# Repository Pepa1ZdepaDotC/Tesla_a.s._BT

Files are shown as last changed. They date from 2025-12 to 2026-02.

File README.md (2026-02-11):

# Tesla 1128A repair and BT upgrade

[Schematic](https://github.com/Pepa1ZdepaDotC/Tesla_BT/blob/main/Tesla_rev_2/Tesla_sextant_BT.pdf)

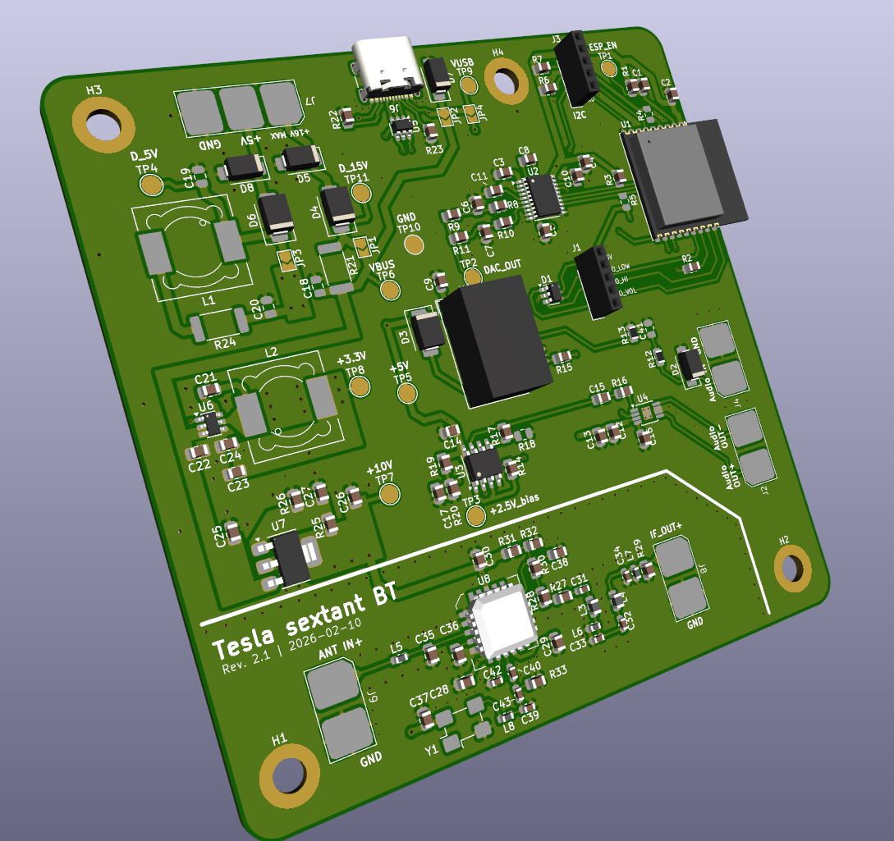
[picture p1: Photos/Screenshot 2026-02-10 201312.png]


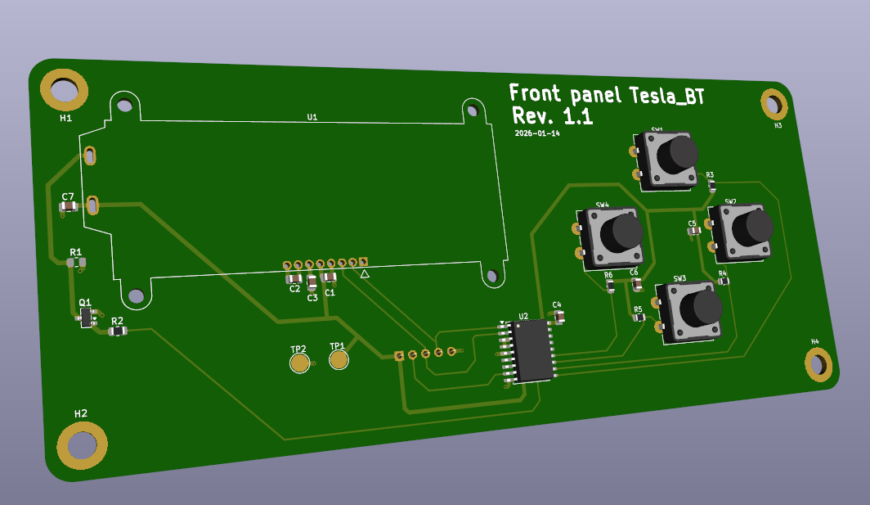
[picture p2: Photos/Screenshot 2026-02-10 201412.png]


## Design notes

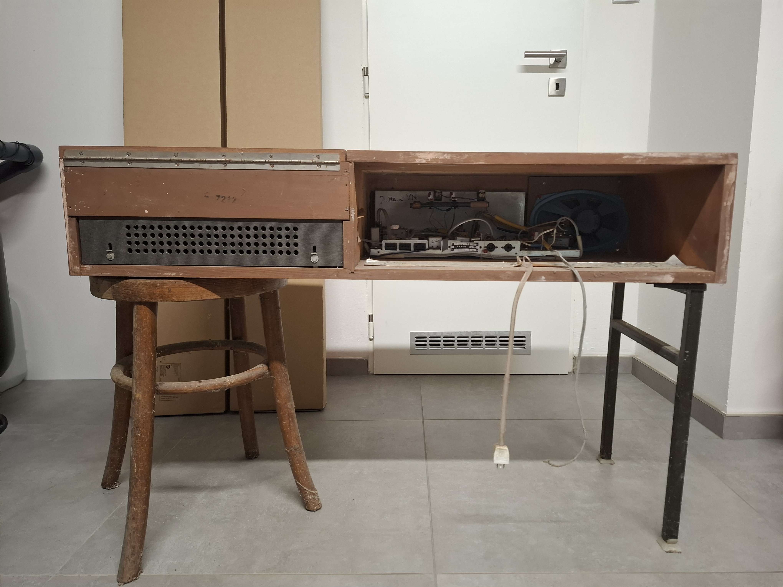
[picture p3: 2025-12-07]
Photos/Back.jpg

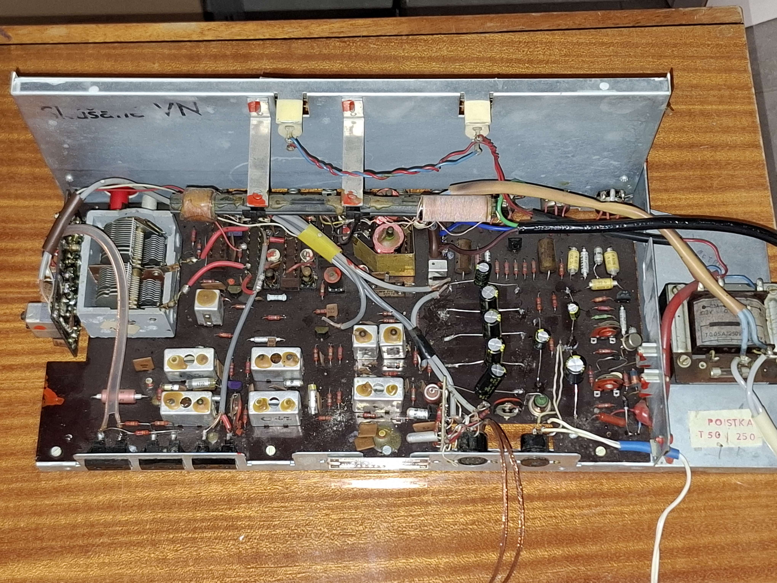
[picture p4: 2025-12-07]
Photos/Up.jpg

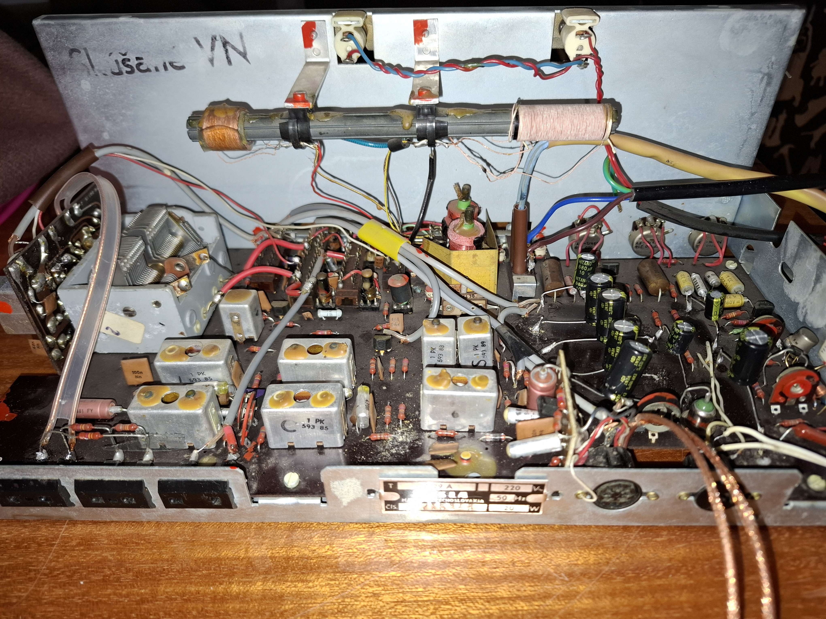
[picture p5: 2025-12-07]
Photos/Side.jpg

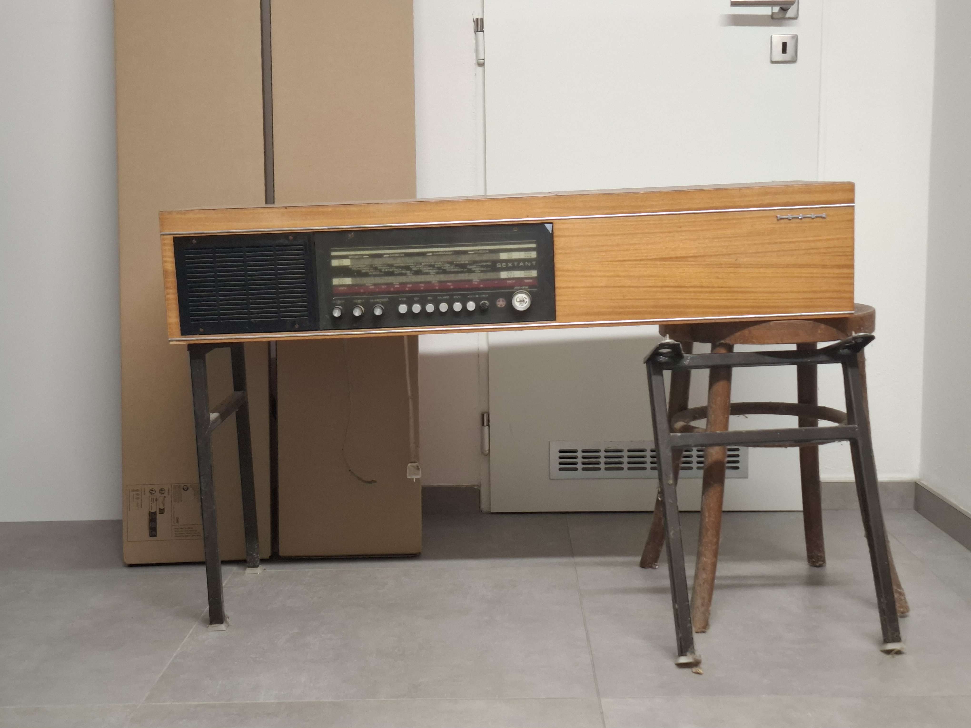
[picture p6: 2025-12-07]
Photos/Front.jpg

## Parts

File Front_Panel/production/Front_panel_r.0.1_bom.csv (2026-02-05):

Designator | Footprint | Quantity | Value | LCSC Part #
C1, C2, C3, C7 | 0805 | 4 | 470nF
C4, C5, C6 | 0805 | 3 | 100nF
J2 | PinSocket_1x05_P2.54mm_Vertical | 1 | Conn_01x05
Q1 | SOT-23 | 1 | BC817
R1 | 0805 | 1 | 0R
R2 | 0805 | 1 | 1K
R3, R4, R5, R6 | 0805 | 4 | 10K
SW1, SW2, SW3, SW4 | SW_PUSH-12mm_Wuerth-430476085716 | 4 | SW_Push
TP1, TP2 | TestPoint_Pad_D3.0mm | 2 | TestPoint
U1 | NHD-C0220BiZ | 1 | NHD-C0220BIZ
U2 | SOIC-18W_7.5x11.6mm_P1.27mm | 1 | MCP23008-xSO

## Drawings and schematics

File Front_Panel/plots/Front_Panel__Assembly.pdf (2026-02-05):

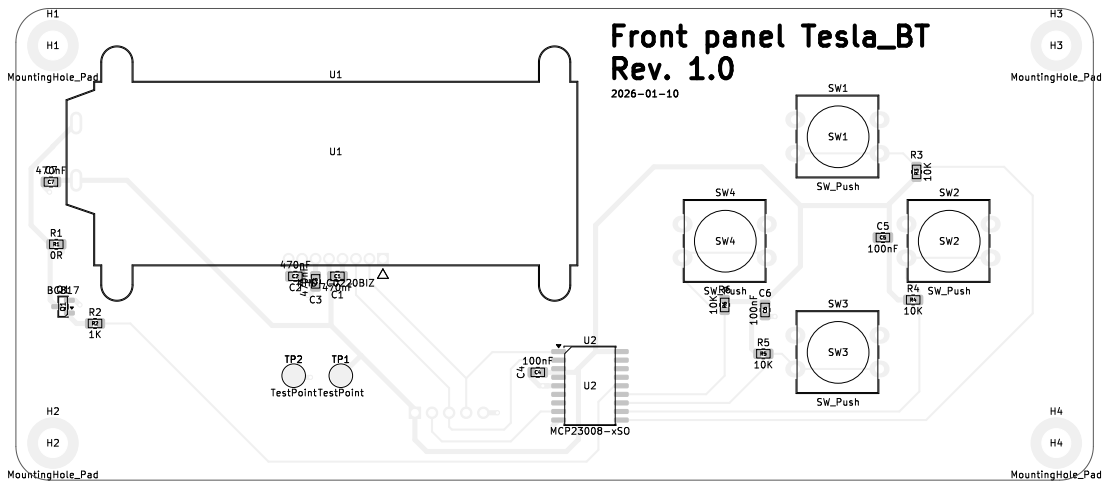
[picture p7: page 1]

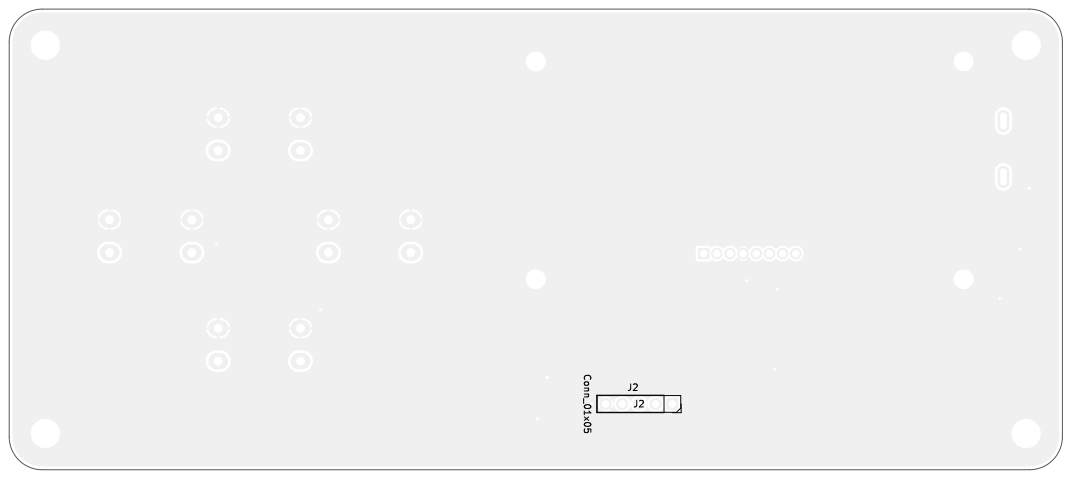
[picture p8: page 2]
D Date: 2026-01-10 KiCad; E.D.A. 9.0.7 Size: A4; Rev: 1.0; Id: /1 Title: Front panel File: Front_Panel.kicad_pcb Sheet: Black; And; White; BOT Board2Pdf:; Black; BOT -; Page 2/2 Conn_01x05

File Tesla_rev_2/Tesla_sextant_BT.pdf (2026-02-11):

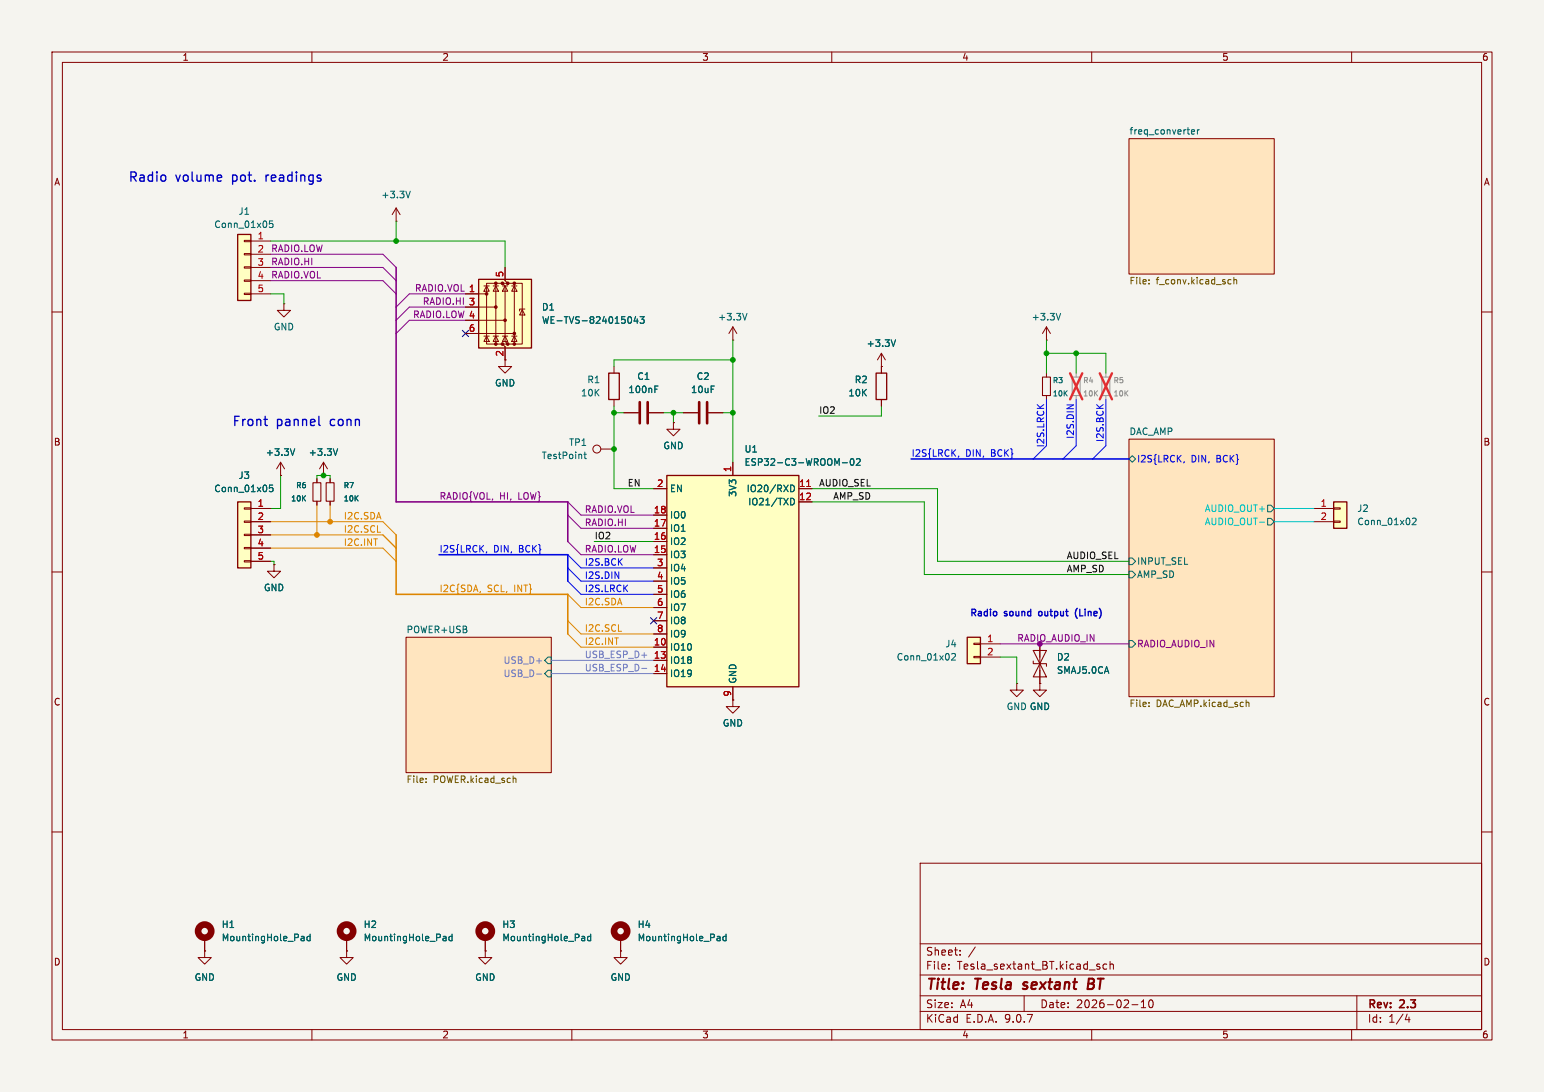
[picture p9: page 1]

I2S.BCK Front pannel conn Radio volume pot. readings
I2C.SCL RADIO.VOL
+3.3V GND

Radio sound output (Line) C2

File: Tesla_sextant_BT.kicad_sch Sheet: / USB_D+ USB_D- POWER+USB

Id: 1/4 Title: Tesla sextant BT

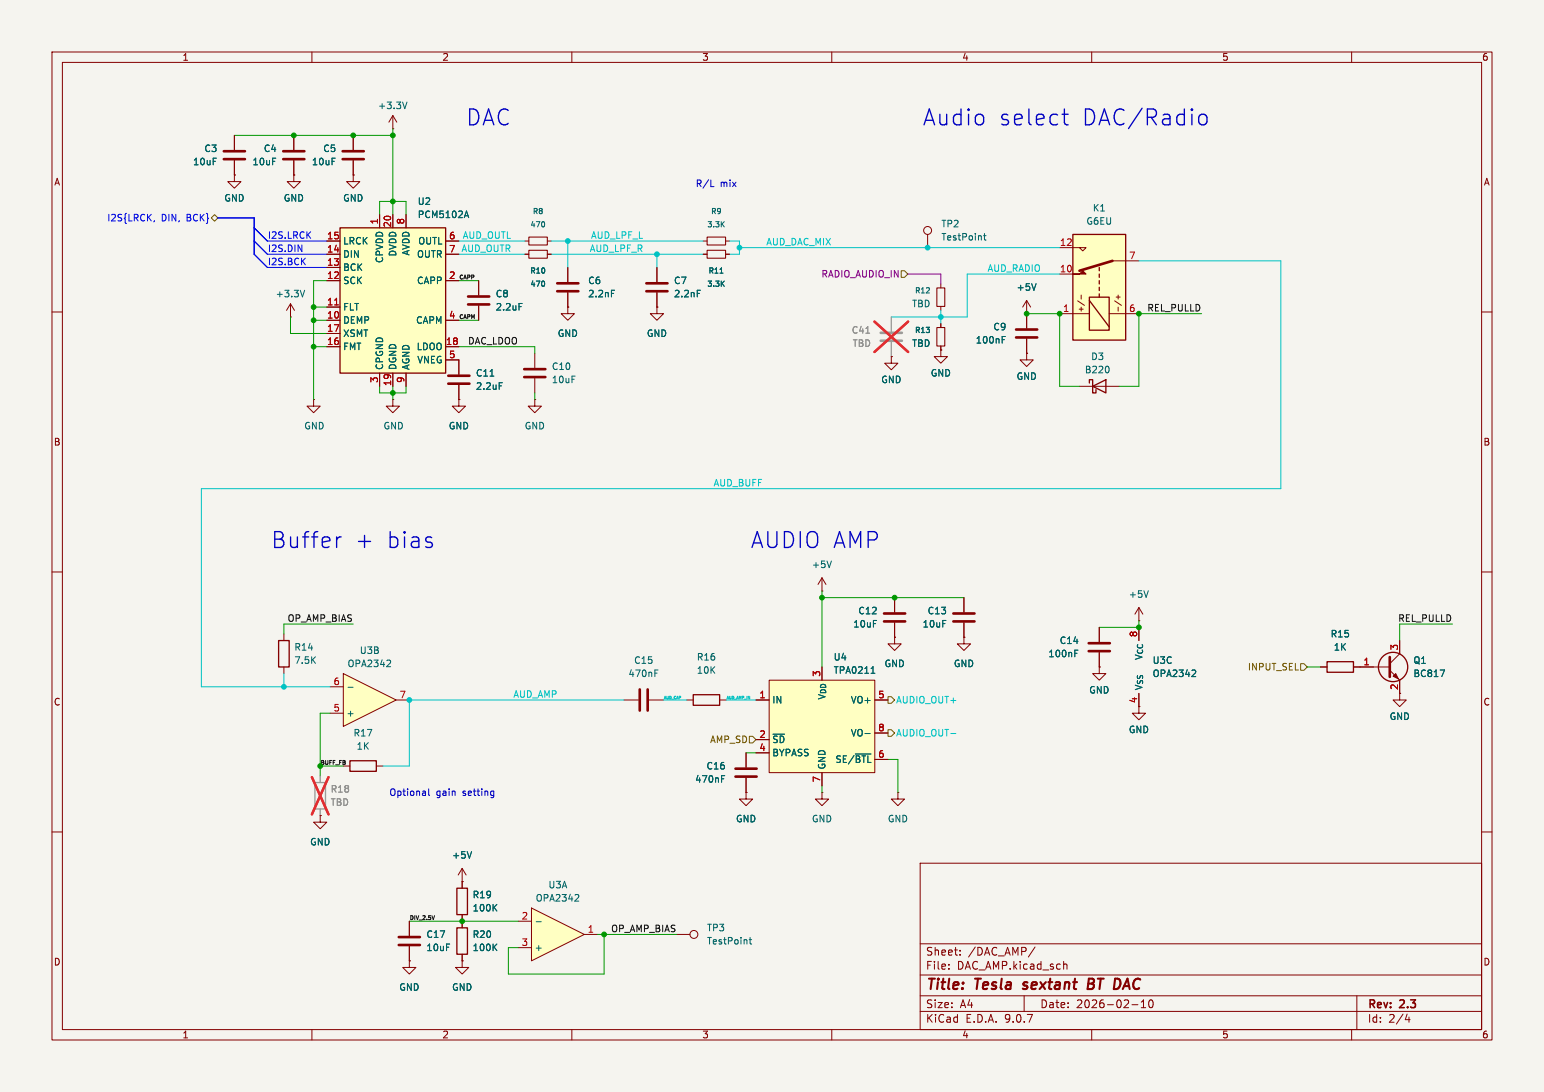
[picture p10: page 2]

9 OUTL 6 OUTR 7 CAPP 2 CAPM 4
2.2uFC8

7 VO+ 5 VO- 8 SE/~{BTL}6 U4 TPA0211

7 VO+ 5 VO- 8 SE/~{BTL}6 R19

File: DAC_AMP.kicad_sch Sheet: /DAC_AMP/
Id: 2/4 Title: Tesla sextant BT DAC

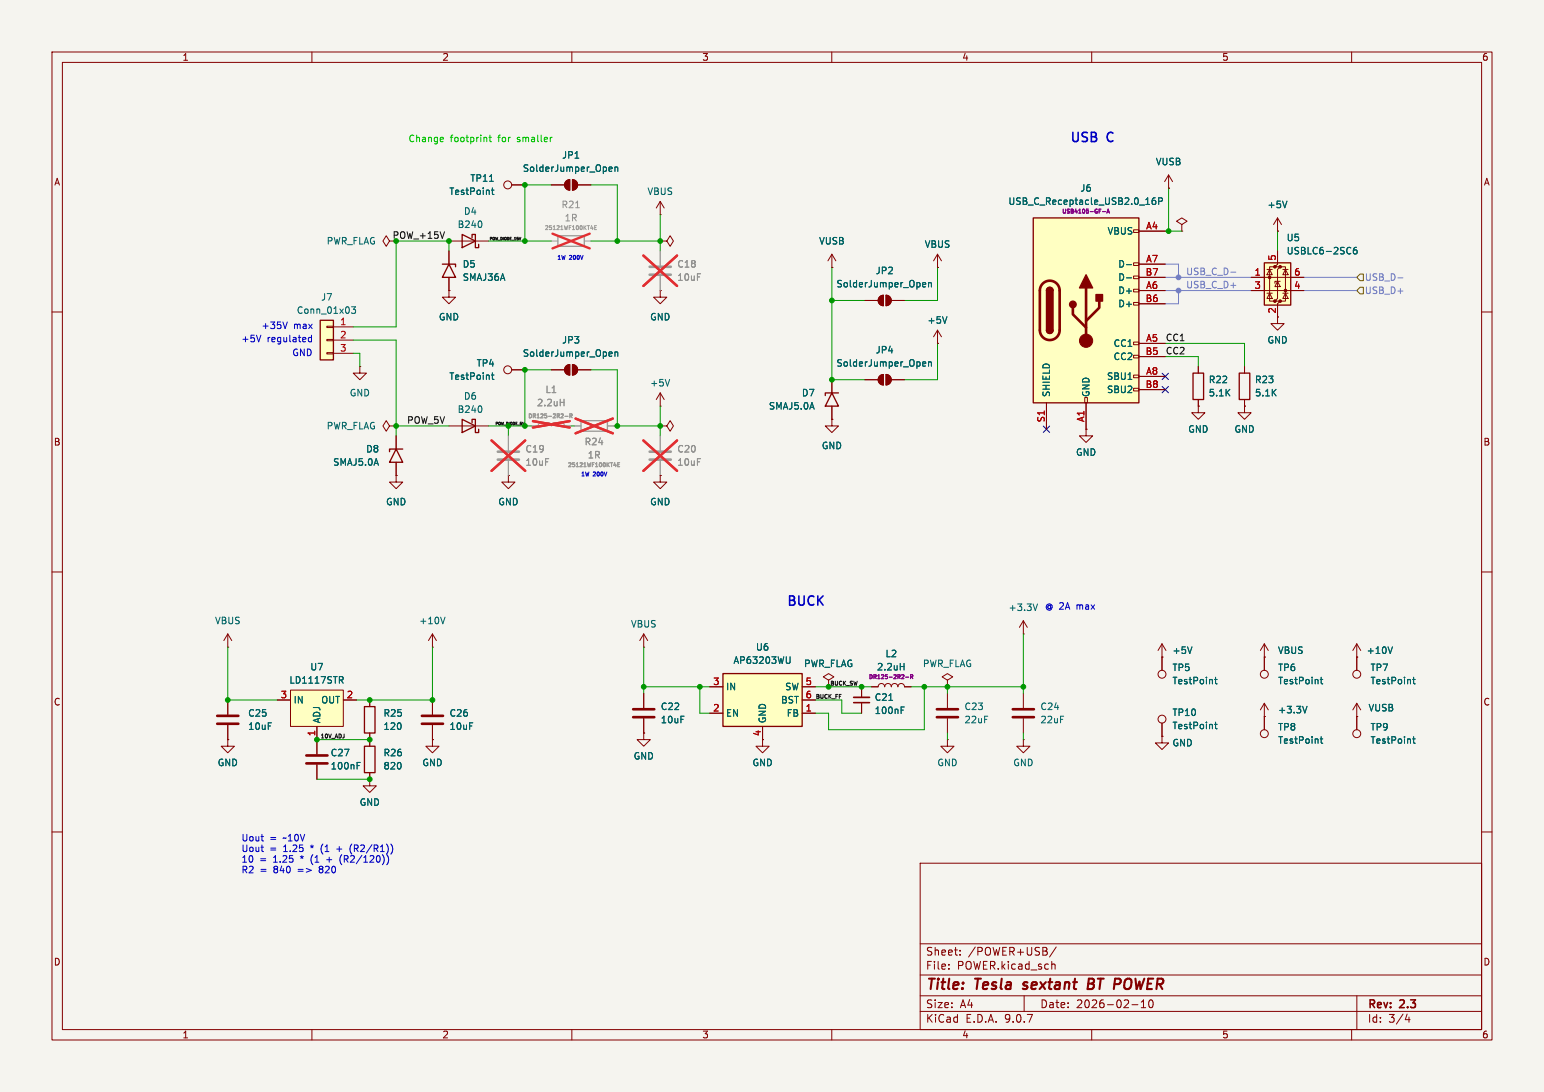
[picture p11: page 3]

4 SW 5 BST 6 FB 1 U6 AP63203WU GND GND

4 SW 5 BST 6 FB 1 GND

File: POWER.kicad_sch Sheet: /POWER+USB/
Id: 3/4 Title: Tesla sextant BT POWER

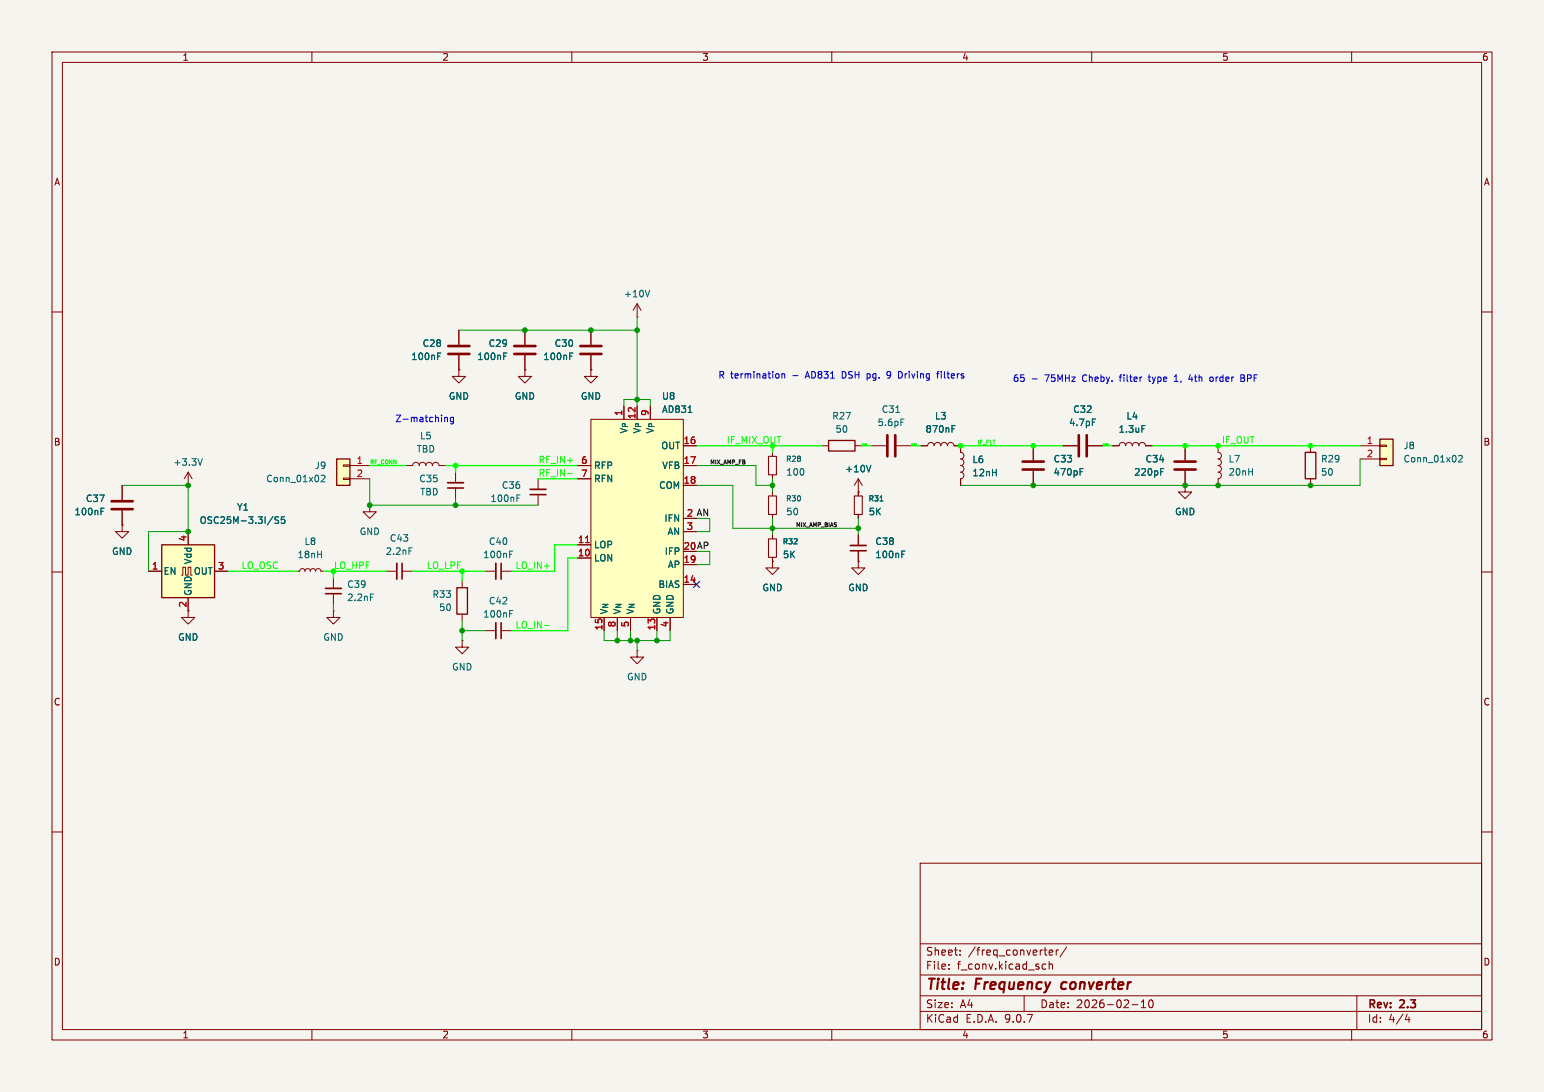
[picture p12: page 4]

Id: 4/4 Title: Frequency converter File: f_conv.kicad_sch Sheet: /freq_converter/ GND

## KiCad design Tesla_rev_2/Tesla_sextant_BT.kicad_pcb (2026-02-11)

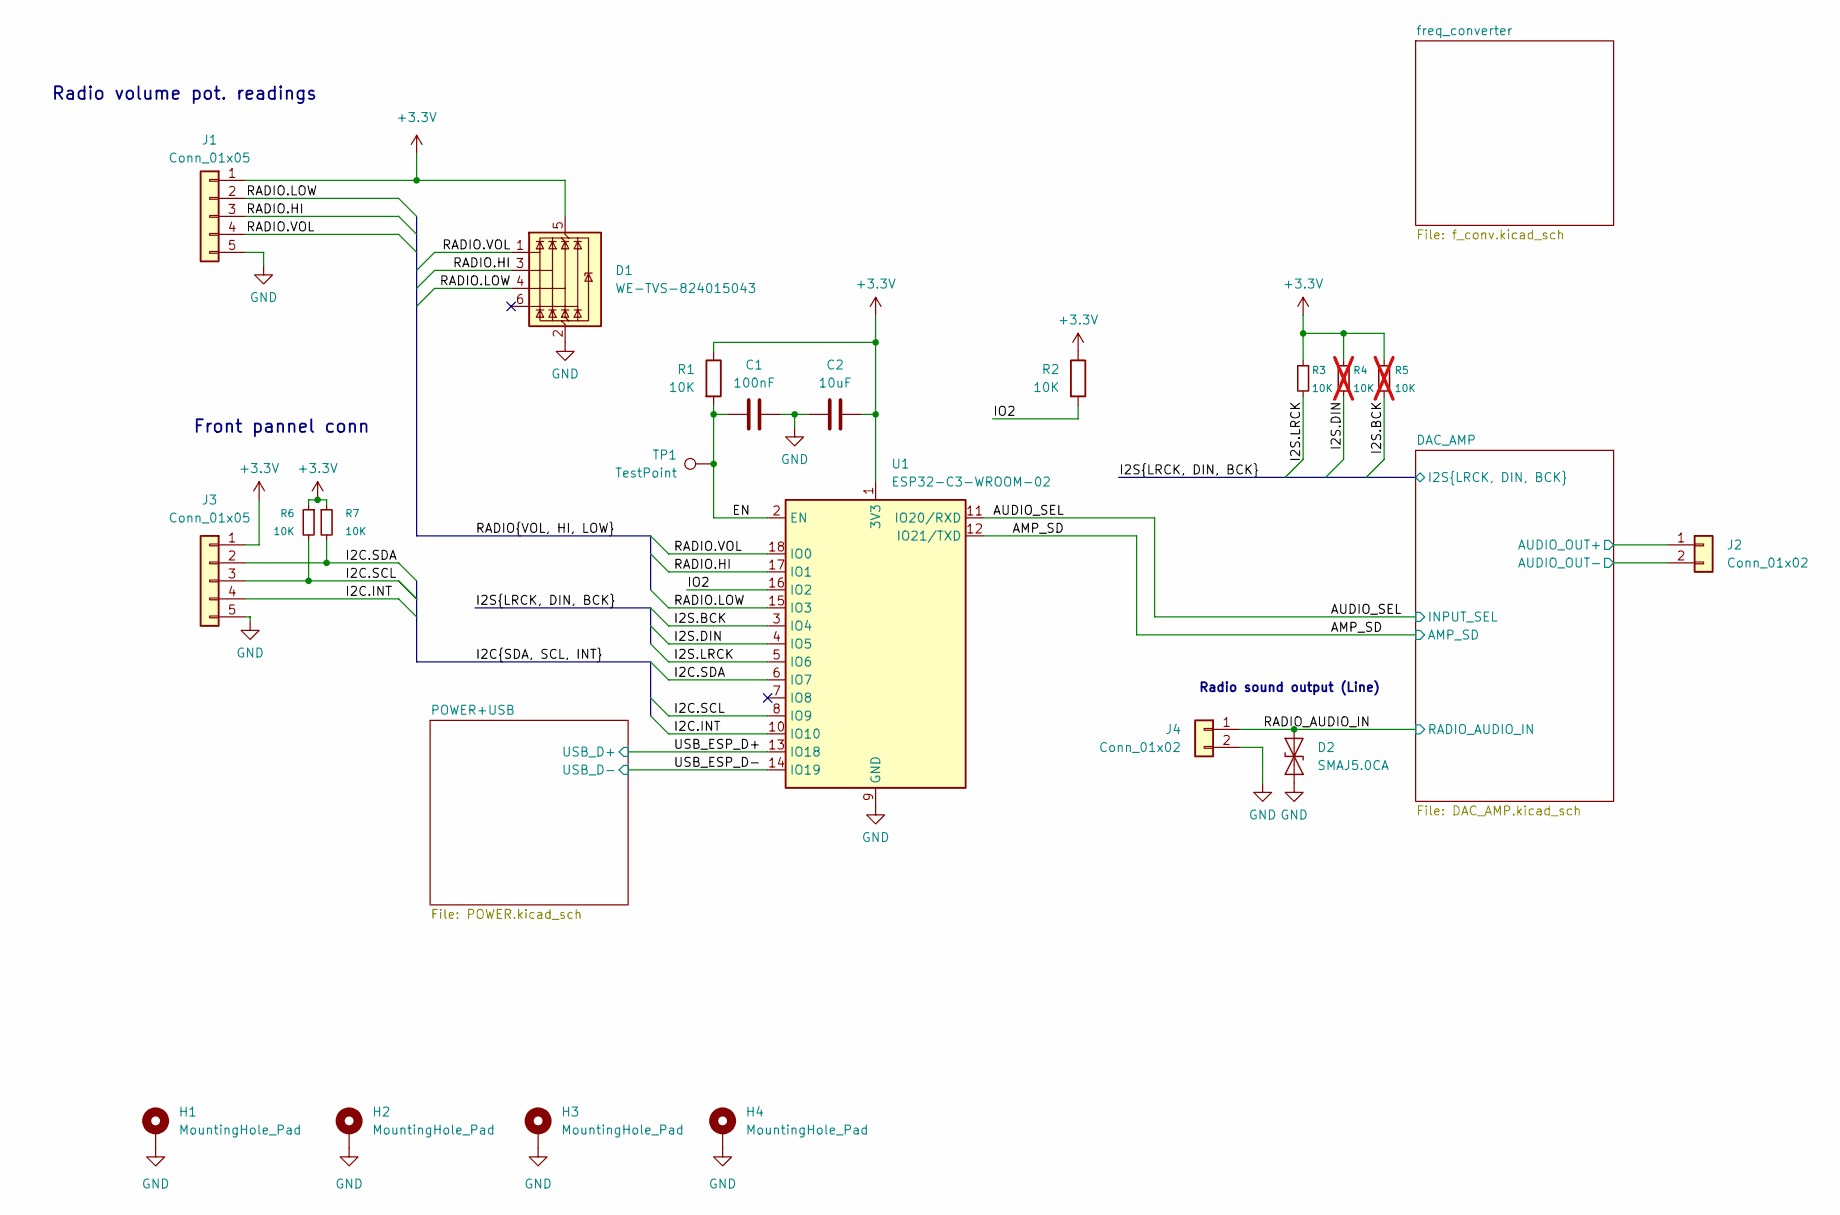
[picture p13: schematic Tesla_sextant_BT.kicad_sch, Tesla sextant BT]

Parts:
C1: 100nF; C_0805_2012Metric
C2: 10uF; C_0805_2012Metric
D1: WE-TVS-824015043; SOT-23-6
D2: SMAJ5.0CA; D_SMA
H1, H2, H3, H4: MountingHole_Pad; MountingHole_4.3mm_M4_DIN965_Pad_TopBottom
J1, J3: Conn_01x05; PinSocket_1x05_P2.00mm_Vertical
J2, J4: Conn_01x02; Conn_Solder_1x02_SMD
R1, R2, R3, R6, R7: 10K; C_0805_2012Metric
R4, R5: 10K; C_0805_2012Metric; not fitted
TP1: TestPoint; TestPoint_Pad_D2.5mm
U1: ESP32-C3-WROOM-02

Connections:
+3.3V: C2.1, D1.5 (VBUS), J1.1, J3.1, R1.1, R2.1, R3.1, R4.1, R5.1, R6.1, R7.1, U1.1 (3V3); also elsewhere on the board
/AMP_SD: U1.12 (IO21/TXD); also elsewhere on the board
/AUDIO_SEL: U1.11 (IO20/RXD); also elsewhere on the board
/DAC_AMP/AUDIO_OUT+: J2.1; also elsewhere on the board
/DAC_AMP/AUDIO_OUT-: J2.2; also elsewhere on the board
/EN: C1.2, R1.2, TP1.1, U1.2 (EN)
/I2C.INT: J3.4, U1.10 (IO10)
/I2C.SCL: J3.3, R6.2, U1.8 (IO9)
/I2C.SDA: J3.2, R7.2, U1.6 (IO7)
/I2S.BCK: R5.2, U1.3 (IO4); also elsewhere on the board
/I2S.DIN: R4.2, U1.4 (IO5); also elsewhere on the board
/I2S.LRCK: R3.2, U1.5 (IO6); also elsewhere on the board
/IO2: R2.2, U1.16 (IO2)
/RADIO.HI: D1.3 (I/O2), J1.3, U1.17 (IO1)
/RADIO.LOW: D1.4 (I/O3), J1.2, U1.15 (IO3)
/RADIO.VOL: D1.1 (I/O1), J1.4, U1.18 (IO0)
/RADIO_AUDIO_IN: D2.1 (A1), J4.1; also elsewhere on the board
/USB_ESP_D+: U1.13 (IO18); also elsewhere on the board
/USB_ESP_D-: U1.14 (IO19); also elsewhere on the board
GND: C1.1, C2.2, D1.2 (GND), D2.2 (A2), H1.1, H2.1, H3.1, H4.1, J1.5, J3.5, J4.2, U1.9 (GND), U1.19 (GND); also elsewhere on the board

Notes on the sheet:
Radio volume pot. readings
Radio sound output (Line)
Front pannel conn

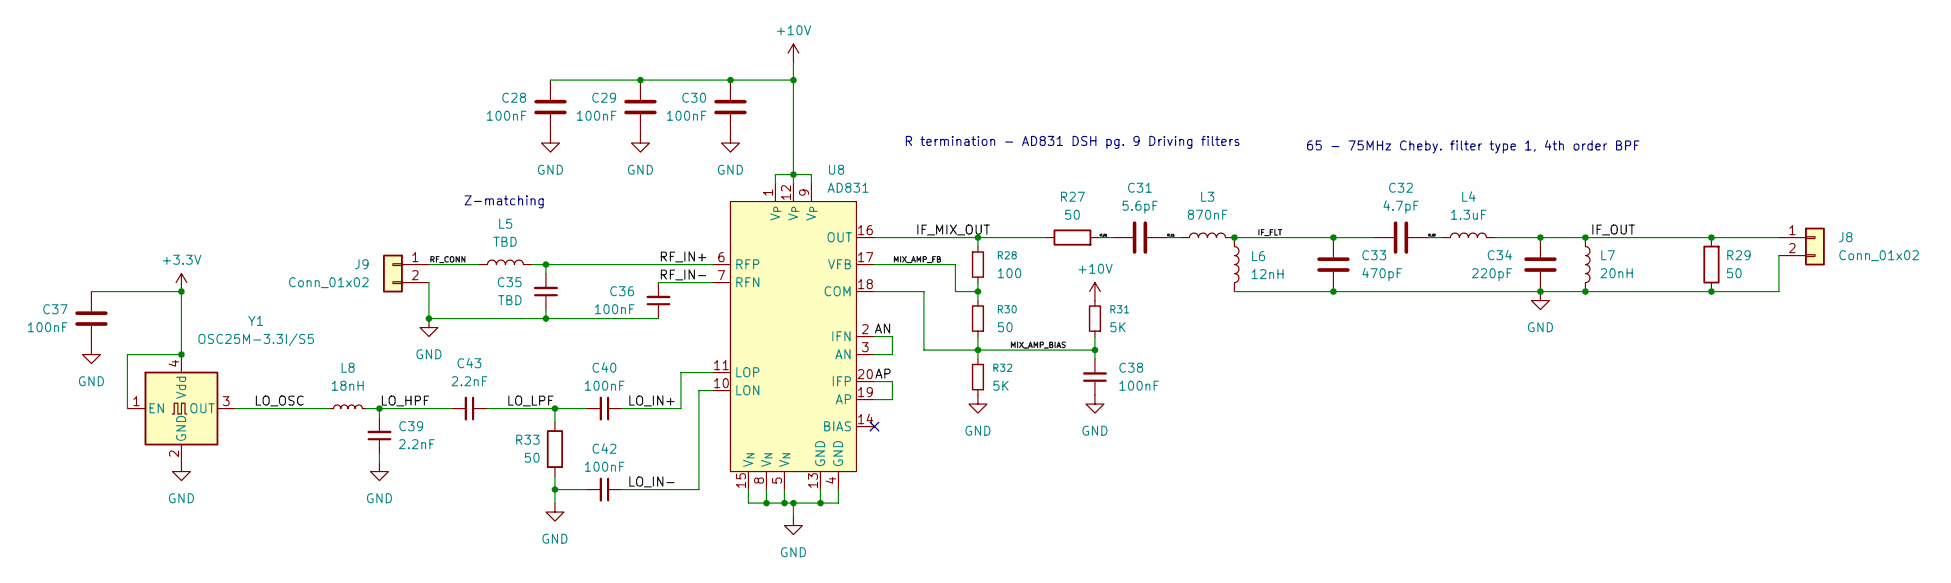
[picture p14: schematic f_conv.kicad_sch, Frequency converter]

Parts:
C28, C29, C30, C36, C37, C38: 100nF; C_0805_2012Metric
C31: 5.6pF; C_0603_1608Metric
C32: 4.7pF; C_0603_1608Metric
C33: 470pF; C_0603_1608Metric
C34: 220pF; C_0603_1608Metric
C35: TBD; C_0805_2012Metric
C39, C43: 2.2nF; C_0603_1608Metric
C40, C42: 100nF; C_0603_1608Metric
J8, J9: Conn_01x02; Conn_Solder_1x02_SMD
L3: 870nF; L_0805_2012Metric; Part_num DL0805-0.082
L4: 1.3uF; L_0805_2012Metric; Part_num DL0805-1.2
L5: TBD; L_0603_1608Metric
L6: 12nH; L_0603_1608Metric; Part_num LQG18HN12NJ00D
L7: 20nH; L_0603_1608Metric
L8: 18nH; L_0603_1608Metric
R27, R29, R30, R33: 50; C_0805_2012Metric
R28: 100; C_0805_2012Metric
R31, R32: 5K; C_0805_2012Metric
U8: AD831; PLCC-20
Y1: OSC25M-3.3I/S5; Oscillator_SMD_Fordahl_DFAS15-4Pin_5.0x3.2mm_HandSoldering

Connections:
+3.3V: C37.2, Y1.1 (EN), Y1.4 (Vdd); also elsewhere on the board
+10V: C28.2, C29.2, C30.2, R31.2, U8.1 (V_{P}), U8.9 (V_{P}), U8.12 (V_{P}); also elsewhere on the board
/freq_converter/AN: U8.2 (IFN), U8.3 (AN)
/freq_converter/AP: U8.19 (AP), U8.20 (IFP)
/freq_converter/IF_C1: C31.2, L3.2
/freq_converter/IF_C3: C32.1, L4.2
/freq_converter/IF_FLT: C32.2, C33.2, L3.1, L6.2
/freq_converter/IF_MIX_OUT: R27.1, R28.1, U8.16 (OUT)
/freq_converter/IF_OUT: C34.2, J8.1, L4.1, L7.1, R29.2
/freq_converter/IF_R1: C31.1, R27.2
/freq_converter/LO_HPF: C39.2, C43.2, L8.2
/freq_converter/LO_IN+: C40.1, U8.11 (LOP)
/freq_converter/LO_IN-: C42.1, U8.10 (LON)
/freq_converter/LO_LPF: C40.2, C43.1, R33.1
/freq_converter/LO_OSC: L8.1, Y1.3 (OUT)
/freq_converter/MIX_AMP_BIAS: C38.2, R30.1, R31.1, R32.2, U8.18 (COM)
/freq_converter/MIX_AMP_FB: R28.2, R30.2, U8.17 (VFB)
/freq_converter/RF_CONN: J9.1, L5.2
/freq_converter/RF_IN+: C35.2, L5.1, U8.6 (RFP)
/freq_converter/RF_IN-: C36.2, U8.7 (RFN)
GND: C28.1, C29.1, C30.1, C33.1, C34.1, C35.1, C36.1, C37.1, C38.1, C39.1, C42.2, J8.2, J9.2, L6.1, L7.2, R29.1, R32.1, R33.2, U8.4 (GND), U8.5 (V_{N}), U8.8 (V_{N}), U8.13 (GND), U8.15 (V_{N}), Y1.2 (GND); also elsewhere on the board

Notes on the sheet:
R termination - AD831 DSH pg. 9 Driving filters
65 - 75MHz Cheby. filter type 1, 4th order BPF
Z-matching

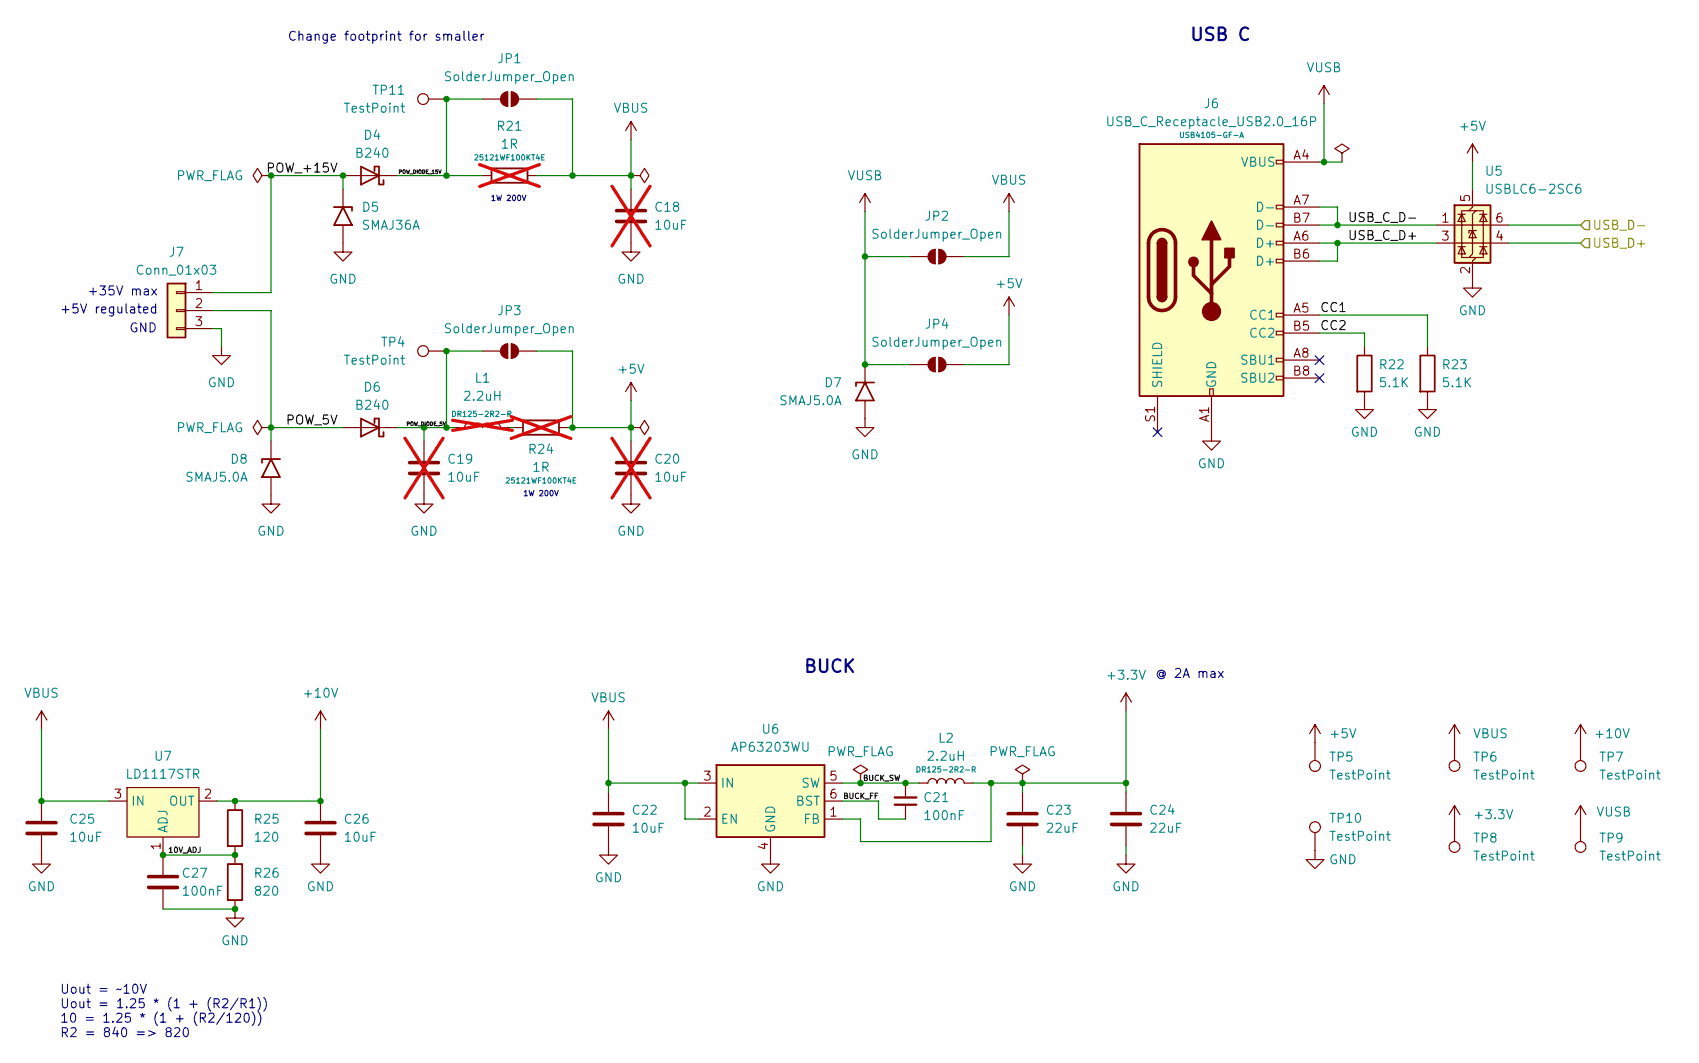
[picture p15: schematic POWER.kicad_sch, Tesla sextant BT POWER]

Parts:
C18, C19, C20: 10uF; C_0805_2012Metric; not fitted
C21, C27: 100nF; C_0805_2012Metric
C22, C25, C26: 10uF; C_0805_2012Metric
C23, C24: 22uF; C_0805_2012Metric
D4, D6: B240; D_SMB
D5: SMAJ36A; D_SMA
D7, D8: SMAJ5.0A; D_SMA
J6: USB_C_Receptacle_USB2.0_16P; USB_C_Receptacle_GCT_USB4105-xx-A_16P_TopMnt_Horizontal; Part_num USB4105-GF-A
J7: Conn_01x03; Conn_Solder_1x03_SMD
JP1, JP2, JP3, JP4: SolderJumper_Open; SolderJumper-2_P1.3mm_Open_TrianglePad1.0x1.5mm
L1: 2.2uH; L_12x12mm_H8mm; Part_num DR125-2R2-R; not fitted
L2: 2.2uH; L_12x12mm_H8mm; Part_num DR125-2R2-R
R21, R24: 1R; R_2512_6332Metric; Part_num 25121WF100KT4E; not fitted
R22, R23: 5.1K; C_0805_2012Metric
R25: 120; C_0805_2012Metric
R26: 820; C_0805_2012Metric
TP4, TP5, TP6, TP7, TP8, TP9, TP10, TP11: TestPoint; TestPoint_Pad_D2.5mm
U5: USBLC6-2SC6; SOT-23-6
U6: AP63203WU; TSOT-23-6
U7: LD1117STR; SOT-223

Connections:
+3.3V: C23.1, C24.1, L2.2, TP8.1, U6.1 (FB); also elsewhere on the board
+5V: C20.1, JP3.2 (B), JP4.2 (B), R24.1, TP5.1, U5.5 (VBUS); also elsewhere on the board
+10V: C26.1, R25.1, TP7.1, U7.2 (OUT), U7.4 (OUT); also elsewhere on the board
/POWER+USB/10V_ADJ: C27.1, R25.2, R26.1, U7.1 (ADJ)
/POWER+USB/BUCK_FF: C21.1, U6.6 (BST)
/POWER+USB/BUCK_SW: C21.2, L2.1, U6.5 (SW)
/POWER+USB/CC1: J6.A5 (CC1), R23.1
/POWER+USB/CC2: J6.B5 (CC2), R22.1
/POWER+USB/POW_5V: D6.2 (A), D8.1 (A1), J7.2
/POWER+USB/POW_+15V: D4.2 (A), D5.1 (A1), J7.1
/POWER+USB/POW_DIODE_5V: C19.1, D6.1 (K), JP3.1 (A), L1.1, TP4.1
/POWER+USB/POW_DIODE_15V: D4.1 (K), JP1.1 (A), R21.2, TP11.1
/POWER+USB/USB_C_D+: J6.A6 (D+), J6.B6 (D+), U5.3 (I/O2)
/POWER+USB/USB_C_D-: J6.A7 (D-), J6.B7 (D-), U5.1 (I/O1)
/USB_ESP_D+: U5.4 (I/O2); also elsewhere on the board
/USB_ESP_D-: U5.6 (I/O1); also elsewhere on the board
GND: C18.2, C19.2, C20.2, C22.2, C23.2, C24.2, C25.2, C26.2, C27.2, D5.2 (A2), D7.2 (A2), D8.2 (A2), J6.A1 (GND), J6.A12 (GND), J6.B1 (GND), J6.B12 (GND), J7.3, R22.2, R23.2, R26.2, TP10.1, U5.2 (GND), U6.4 (GND); also elsewhere on the board
unnamed: L1.2, R24.2
VBUS: C18.1, C22.1, C25.1, JP1.2 (B), JP2.2 (B), R21.1, TP6.1, U6.2 (EN), U6.3 (IN), U7.3 (IN)
VUSB: D7.1 (A1), J6.A4 (VBUS), J6.A9 (VBUS), J6.B4 (VBUS), J6.B9 (VBUS), JP2.1 (A), JP4.1 (A), TP9.1

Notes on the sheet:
Uout = ~10V Uout = 1.25 * (1 + (R2/R1)) 10 = 1.25 * (1 + (R2/120)) R2 = 840 => 820
@ 2A max
+5V regulated
GND
1W 200V
+35V max
Change footprint for smaller
BUCK
USB C

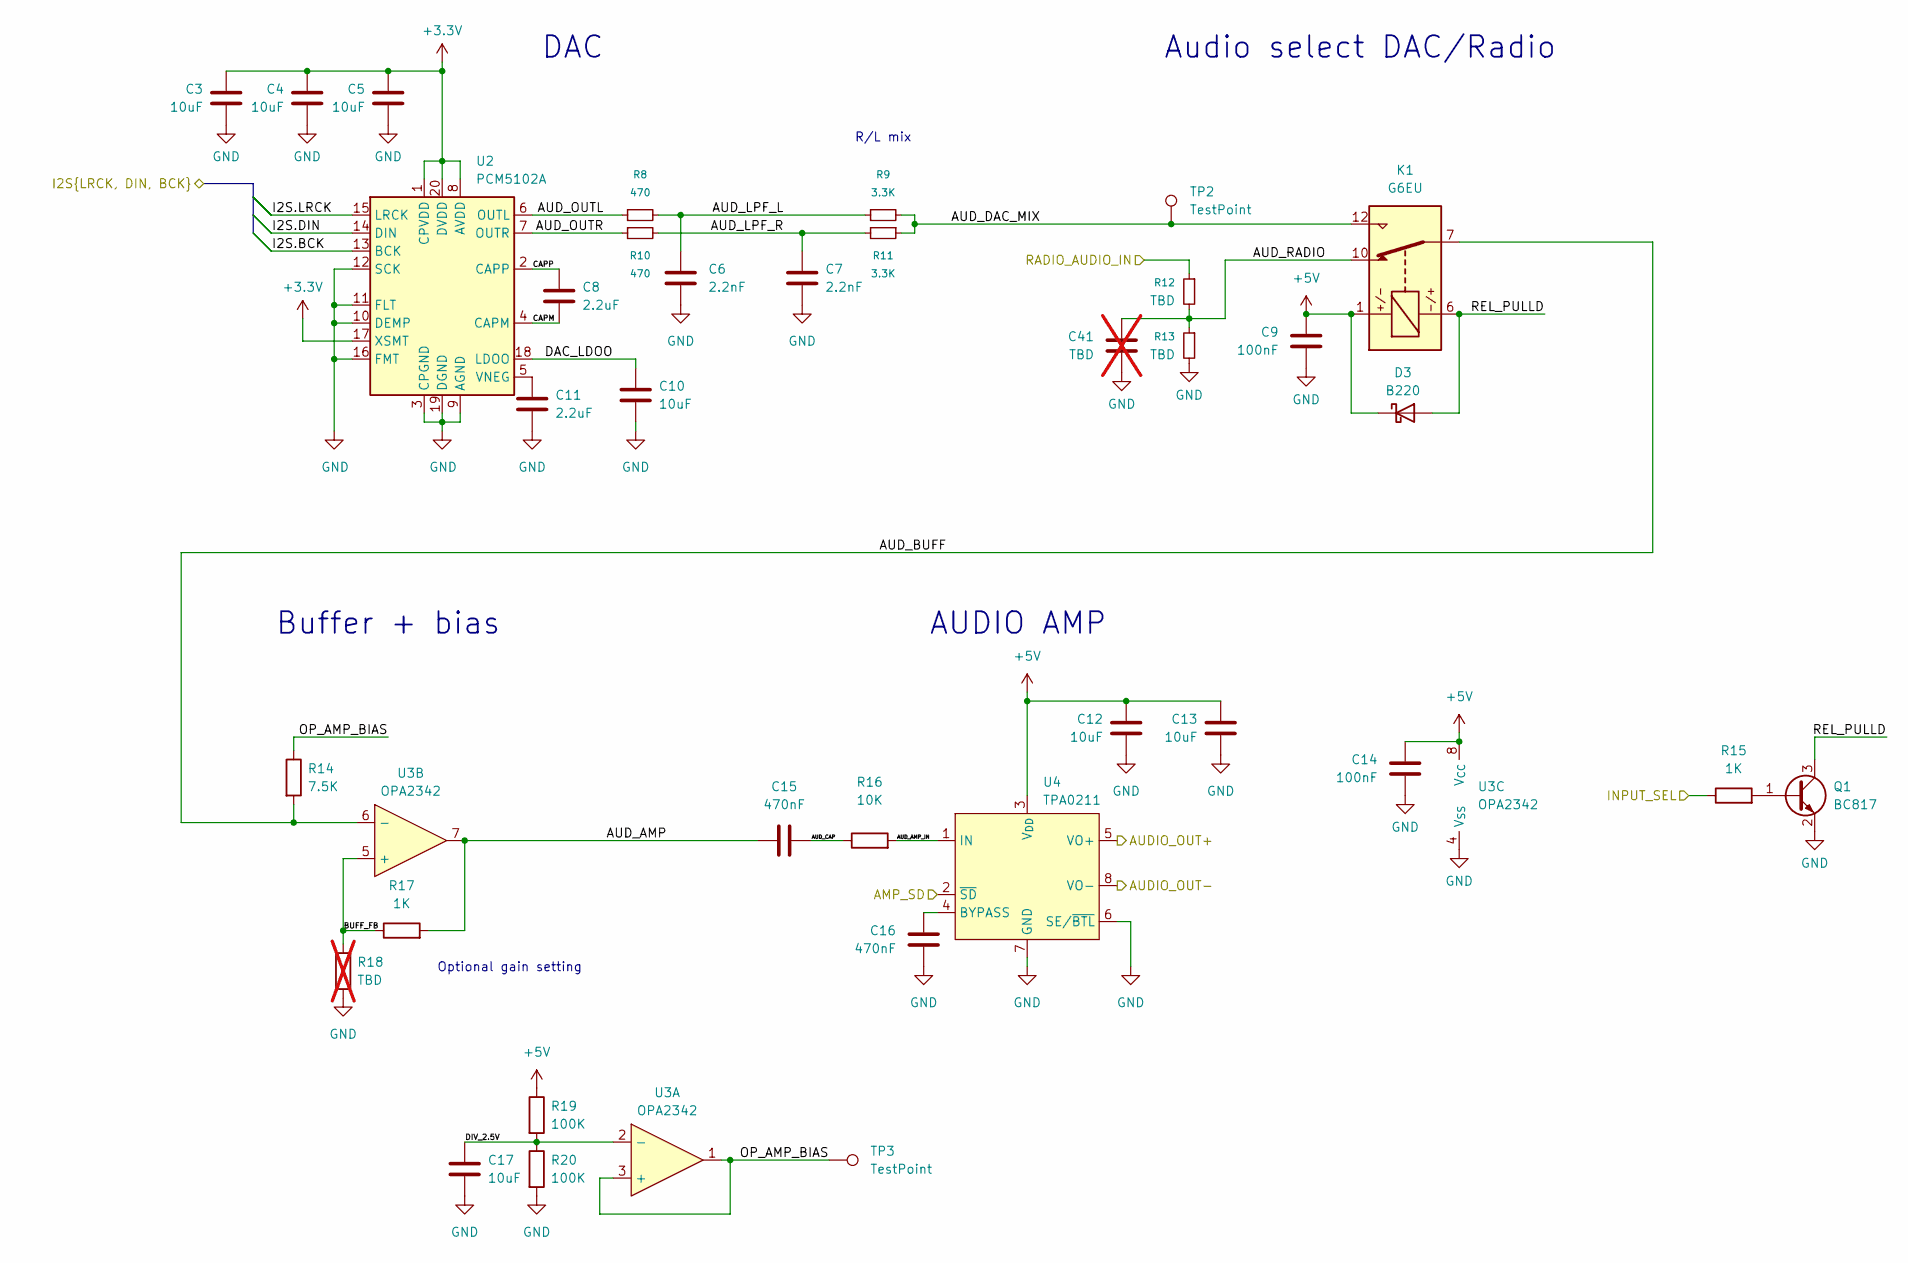
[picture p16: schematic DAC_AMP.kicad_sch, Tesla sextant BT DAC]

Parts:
C3, C4, C5, C10, C12, C13, C17: 10uF; C_0805_2012Metric
C6, C7: 2.2nF; C_0805_2012Metric
C8, C11: 2.2uF; C_0805_2012Metric
C9, C14: 100nF; C_0805_2012Metric
C15, C16: 470nF; C_0805_2012Metric
C41: TBD; C_0805_2012Metric; not fitted
D3: B220; D_SMB
K1: G6EU; Relay_SPDT_Omron_G6E
Q1: BC817; SOT-23
R8, R10: 470; C_0805_2012Metric
R9, R11: 3.3K; C_0805_2012Metric
R12, R13: TBD; R_0805_2012Metric
R14: 7.5K; C_0805_2012Metric
R15, R17: 1K; C_0805_2012Metric
R16: 10K; C_0805_2012Metric
R18: TBD; C_0805_2012Metric; not fitted
R19, R20: 100K; C_0805_2012Metric
TP2, TP3: TestPoint; TestPoint_Pad_D2.5mm
U2: PCM5102A; TSSOP-20_4.4x6.5mm_P0.65mm
U3: OPA2342; SOIC-8_3.9x4.9mm_P1.27mm
U4: TPA0211; HVSSOP-8-1EP_3x3mm_P0.65mm_EP1.57x1.89mm_ThermalVias

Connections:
+3.3V: C3.1, C4.1, C5.1, U2.1 (CPVDD), U2.8 (AVDD), U2.17 (XSMT), U2.20 (DVDD); also elsewhere on the board
+5V: C9.1, C12.1, C13.1, C14.1, D3.1 (K), K1.1, R19.1, U3.8 (V_{CC}), U4.3 (V_{DD}); also elsewhere on the board
/AMP_SD: U4.2 (~SD); also elsewhere on the board
/AUDIO_SEL: R15.1; also elsewhere on the board
/DAC_AMP/AUDIO_OUT+: U4.5 (VO+); also elsewhere on the board
/DAC_AMP/AUDIO_OUT-: U4.8 (VO-); also elsewhere on the board
/DAC_AMP/AUD_AMP: C15.1, R17.2, U3.7
/DAC_AMP/AUD_AMP_IN: R16.2, U4.1 (IN)
/DAC_AMP/AUD_BUFF: K1.7, R14.2, U3.6 (-)
/DAC_AMP/AUD_CAP: C15.2, R16.1
/DAC_AMP/AUD_DAC_MIX: K1.12, R9.2, R11.1, TP2.1
/DAC_AMP/AUD_LPF_L: C6.1, R8.2, R9.1
/DAC_AMP/AUD_LPF_R: C7.1, R10.2, R11.2
/DAC_AMP/AUD_OUTL: R8.1, U2.6 (OUTL)
/DAC_AMP/AUD_OUTR: R10.1, U2.7 (OUTR)
/DAC_AMP/AUD_RADIO: C41.1, K1.10, R12.2, R13.1
/DAC_AMP/BUFF_FB: R17.1, R18.2, U3.5 (+)
/DAC_AMP/CAPM: C8.2, U2.4 (CAPM)
/DAC_AMP/CAPP: C8.1, U2.2 (CAPP)
/DAC_AMP/DAC_LDOO: C10.1, U2.18 (LDOO)
/DAC_AMP/DIV_2.5V: C17.1, R19.2, R20.1, U3.2 (-)
/DAC_AMP/OP_AMP_BIAS: R14.1, TP3.1, U3.1, U3.3 (+)
/DAC_AMP/REL_PULLD: D3.2 (A), K1.6, Q1.3 (C)
/I2S.BCK: U2.13 (BCK); also elsewhere on the board
/I2S.DIN: U2.14 (DIN); also elsewhere on the board
/I2S.LRCK: U2.15 (LRCK); also elsewhere on the board
/RADIO_AUDIO_IN: R12.1; also elsewhere on the board
GND: C3.2, C4.2, C5.2, C6.2, C7.2, C9.2, C10.2, C11.2, C12.2, C13.2, C14.2, C16.2, C17.2, C41.2, Q1.2 (E), R13.2, R18.1, R20.2, U2.3 (CPGND), U2.9 (AGND), U2.10 (DEMP), U2.11 (FLT), U2.12 (SCK), U2.16 (FMT), U2.19 (DGND), U3.4 (V_{SS}), U4.6 (SE/~BTL), U4.7 (GND); also elsewhere on the board
unnamed: Q1.1 (B), R15.2
unnamed: C11.1, U2.5 (VNEG)
unnamed: C16.1, U4.4 (BYPASS)

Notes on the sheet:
Audio select DAC/Radio
AUDIO AMP
R/L mix
Buffer + bias
DAC
Optional gain setting

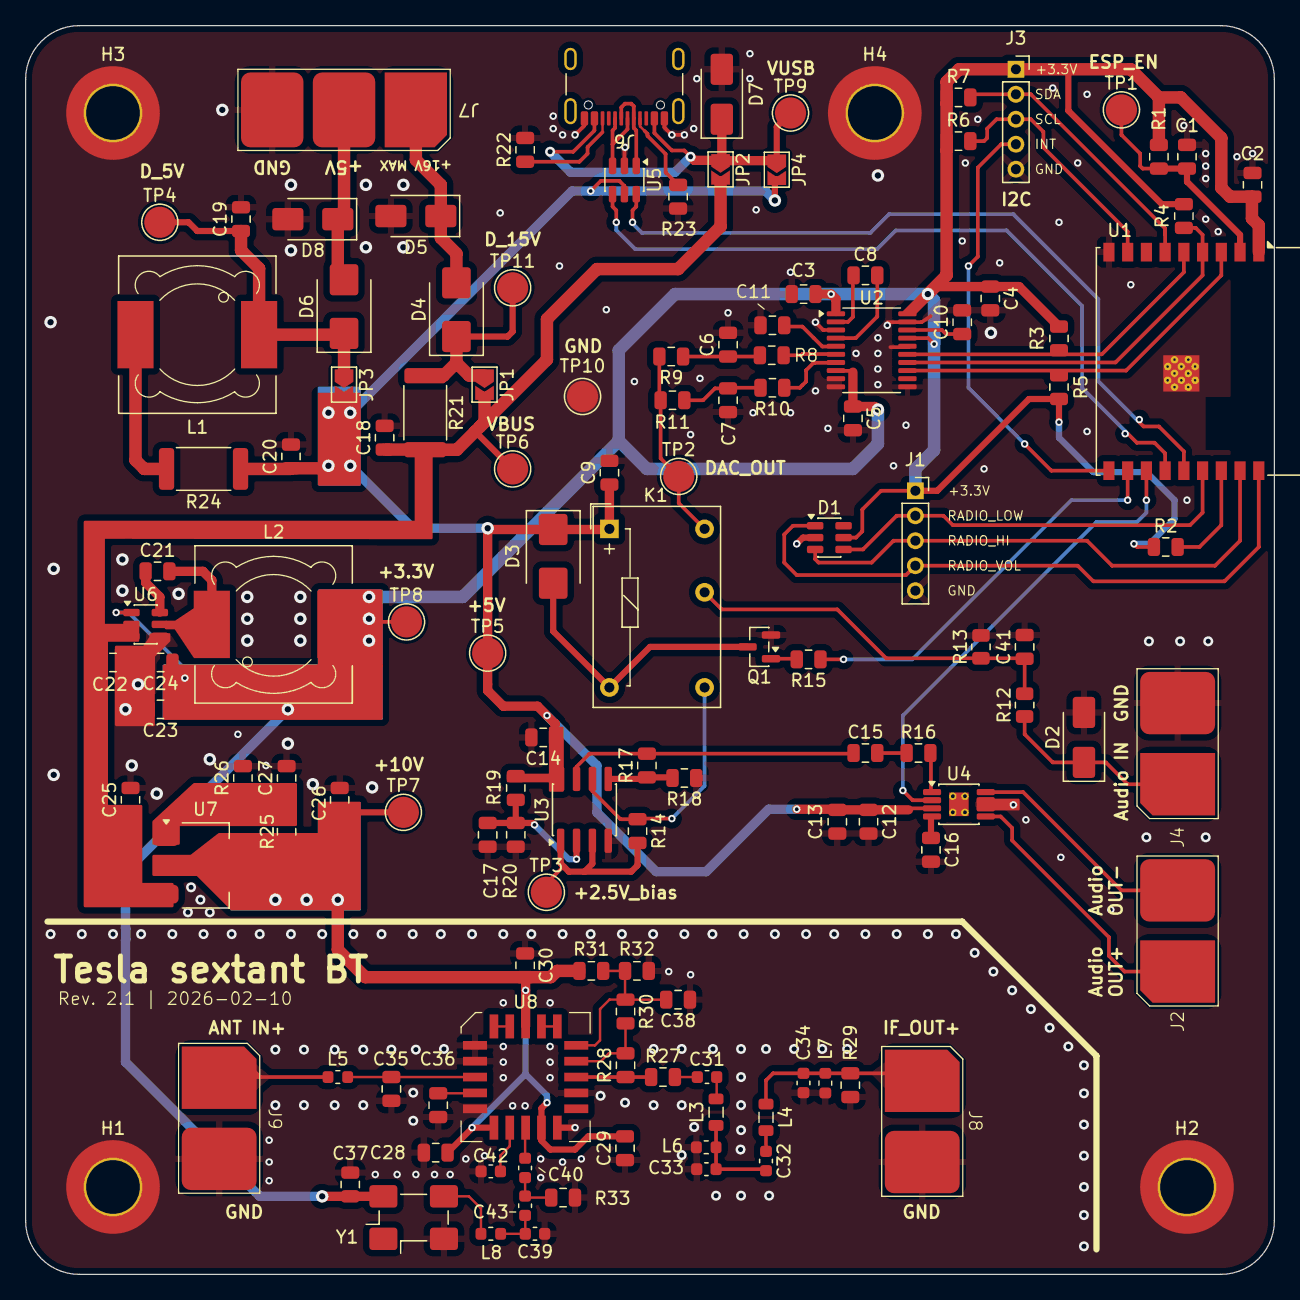
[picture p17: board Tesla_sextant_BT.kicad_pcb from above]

Board: 4 copper layers, 100.0 x 100.0 mm, 130 parts (0 on the bottom side), 74 nets.

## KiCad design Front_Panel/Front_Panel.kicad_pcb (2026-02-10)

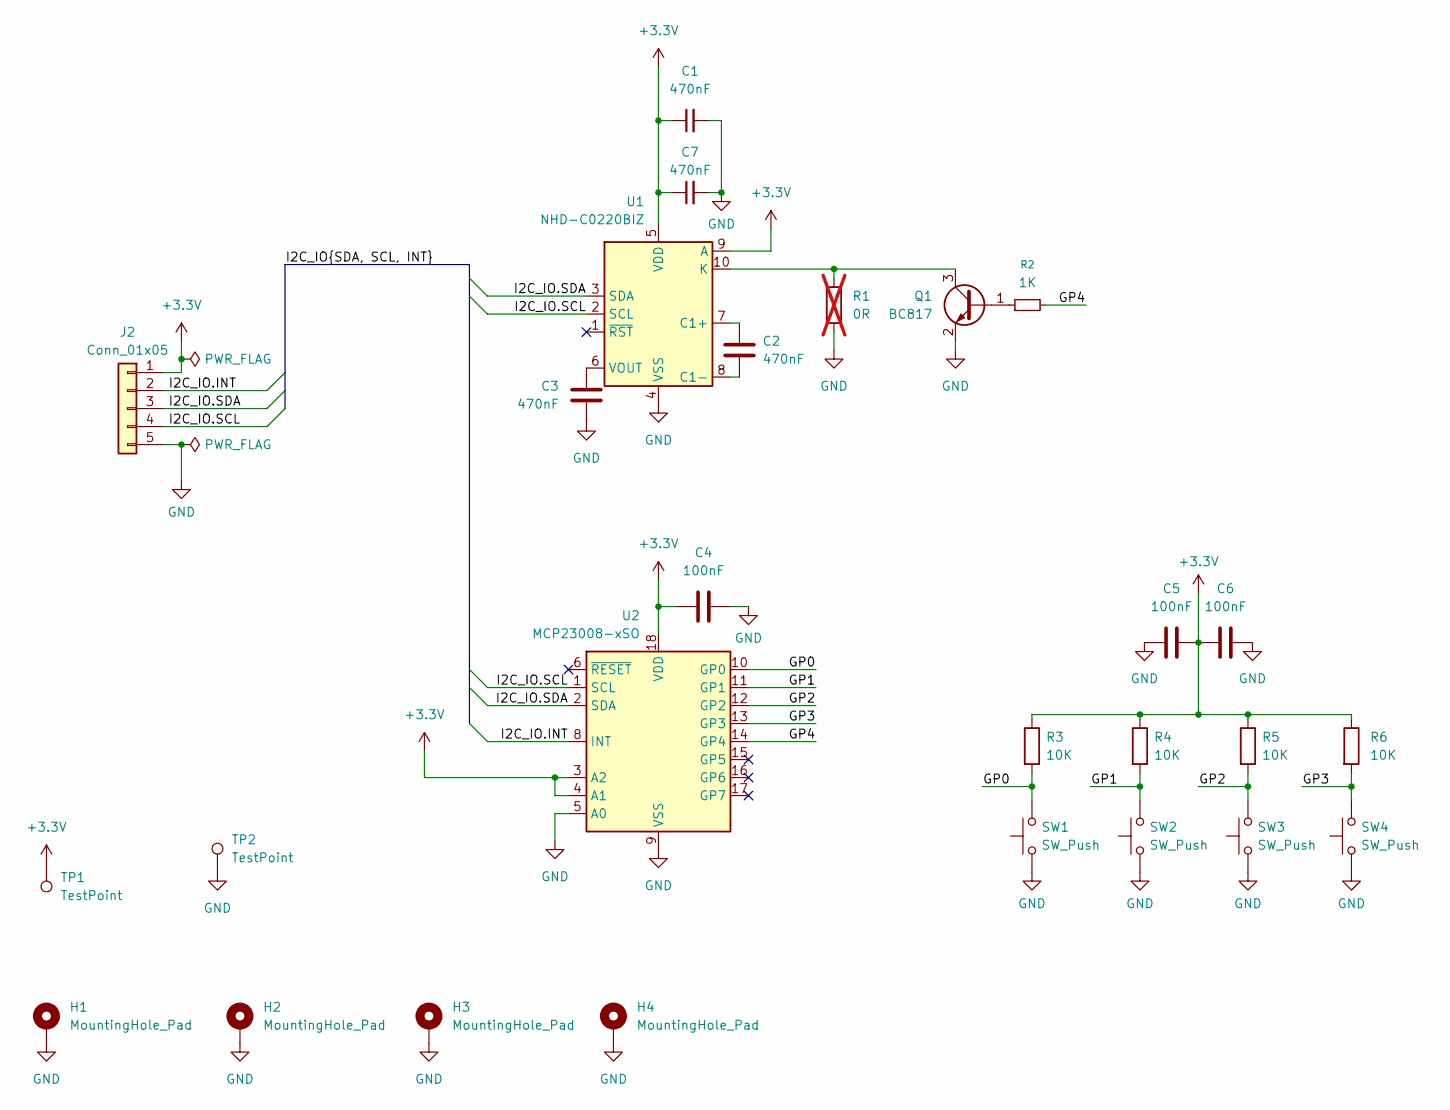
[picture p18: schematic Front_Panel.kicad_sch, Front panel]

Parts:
C1, C2, C3, C7: 470nF; C_0805_2012Metric
C4, C5, C6: 100nF; C_0805_2012Metric
H1, H2, H3, H4: MountingHole_Pad; MountingHole_4.3mm_M4_DIN965_Pad_TopBottom
J2: Conn_01x05; PinSocket_1x05_P2.54mm_Vertical
Q1: BC817; SOT-23
R1: 0R; R_0805_2012Metric; not fitted
R2: 1K; R_0805_2012Metric
R3, R4, R5, R6: 10K; R_0805_2012Metric
SW1, SW2, SW3, SW4: SW_Push; SW_PUSH-12mm_Wuerth-430476085716
TP1, TP2: TestPoint; TestPoint_Pad_D3.0mm
U1: NHD-C0220BIZ; NHD-C0220BiZ
U2: MCP23008-xSO; SOIC-18W_7.5x11.6mm_P1.27mm

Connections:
+3.3V: C1.1, C4.1, C5.2, C6.1, C7.1, J2.1, R3.1, R4.1, R5.1, R6.1, TP1.1, U1.5 (VDD), U1.9 (A), U2.3 (A2), U2.4 (A1), U2.18 (VDD)
/GP0: R3.2, SW1.2, U2.10 (GP0)
/GP1: R4.2, SW2.2, U2.11 (GP1)
/GP2: R5.2, SW3.2, U2.12 (GP2)
/GP3: R6.2, SW4.2, U2.13 (GP3)
/GP4: R2.2, U2.14 (GP4)
/I2C_IO.INT: J2.2, U2.8 (INT)
/I2C_IO.SCL: J2.4, U1.2 (SCL), U2.1 (SCL)
/I2C_IO.SDA: J2.3, U1.3 (SDA), U2.2 (SDA)
GND: C1.2, C3.2, C4.2, C5.1, C6.2, C7.2, H1.1, H2.1, H3.1, H4.1, J2.5, Q1.2 (E), R1.2, SW1.1, SW2.1, SW3.1, SW4.1, TP2.1, U1.4 (VSS), U2.5 (A0), U2.9 (VSS)
unnamed: Q1.1 (B), R2.1
unnamed: Q1.3 (C), R1.1, U1.10 (K)
unnamed: C2.1, U1.7 (C1+)
unnamed: C2.2, U1.8 (C1-)
unnamed: C3.1, U1.6 (VOUT)

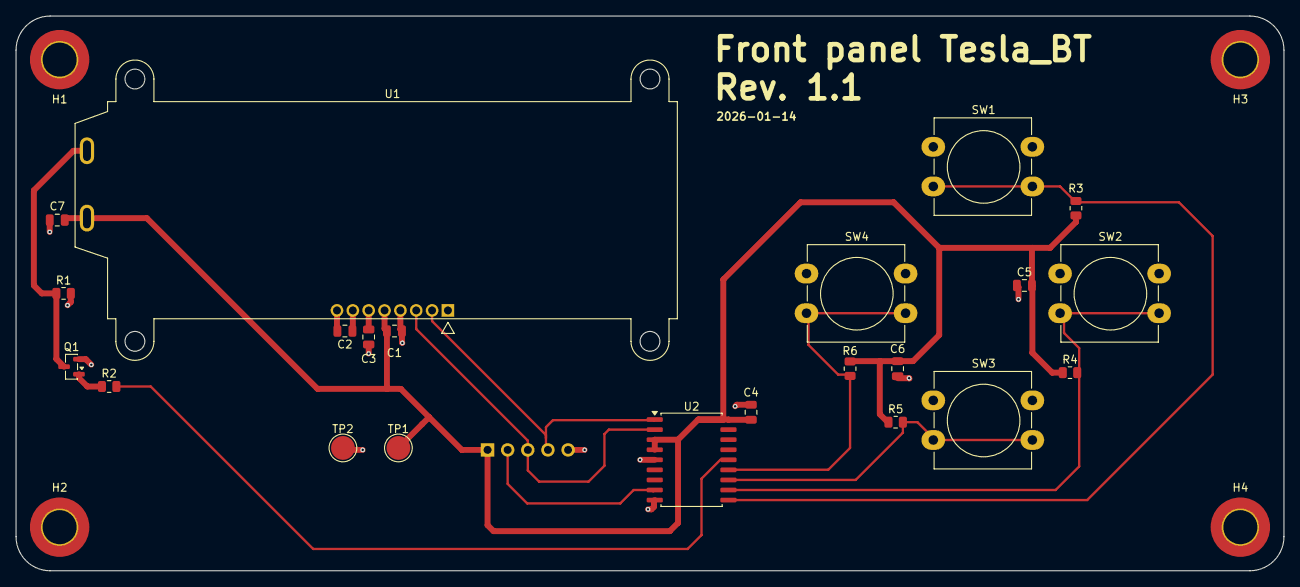
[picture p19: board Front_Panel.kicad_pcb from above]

Board: 2 copper layers, 160.0 x 70.0 mm, 27 parts (1 on the bottom side), 15 nets.

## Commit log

2025-11-29 Changed link to schematic pdf
2025-12-17 revision 3
    [DAC_AMP.kicad_sch, Front_Panel.kicad_pcb, Front_Panel.kicad_sch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]
2026-02-05 Rev 2.3, schematic and footprint fixes, prepared for layout
    [DAC_AMP.kicad_sch, Front_Panel.kicad_pcb, Front_Panel.kicad_sch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]
2026-02-10 added PCB layou
    [DAC_AMP.kicad_sch, Front_Panel.kicad_pcb, POWER.kicad_sch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]
2026-02-11 schematic fixes and pcb layout
    [Tesla_sextant_BT.kicad_pcb]
